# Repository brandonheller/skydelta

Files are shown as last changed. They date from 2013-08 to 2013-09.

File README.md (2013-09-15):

CAUTION: EXPERIMENTAL!

SkyDelta is a new type of 3D printer that employs tensioned lines for motion, rather than linear axes.  This repository includes all the OpenSCAD parts files needed to replicate the design and play with it yourself, under a [Creative Commons Attribution-NonCommercial license (CC BY-NC)](http://creativecommons.org/licenses/by-nc/3.0/). 

Designed by Brandon Heller in California (mostly, plus some design done over the Pacific).  The name refers to Skycam, which flies over football and athletic fields to provide great camera shots, using carefully-controlled high-tension lines.

SkyDelta builds on the triangular prism frame of an extrusion-based Linear Delta of your choice, like a Kossel Mini or Cerberus Pup.  It ditches the linear rails, carriages, ball joints, control rods, belts and pulleys.  It adds Spectra line, printed parts, bearings, standoffs, and three springs.

On the plus side, it can potentially be cheaper, simpler, and faster to build, plus yield a larger build envelope.  On the down side, it may be harder to calibrate, requires new firmware, and may simply not print well.  

Honestly, I don't know if it'll work, but it seems fun to try.  The parts are carefully designed and all have seen tweaks from printing and assembling them, but the whole assembly will likely need tuning.

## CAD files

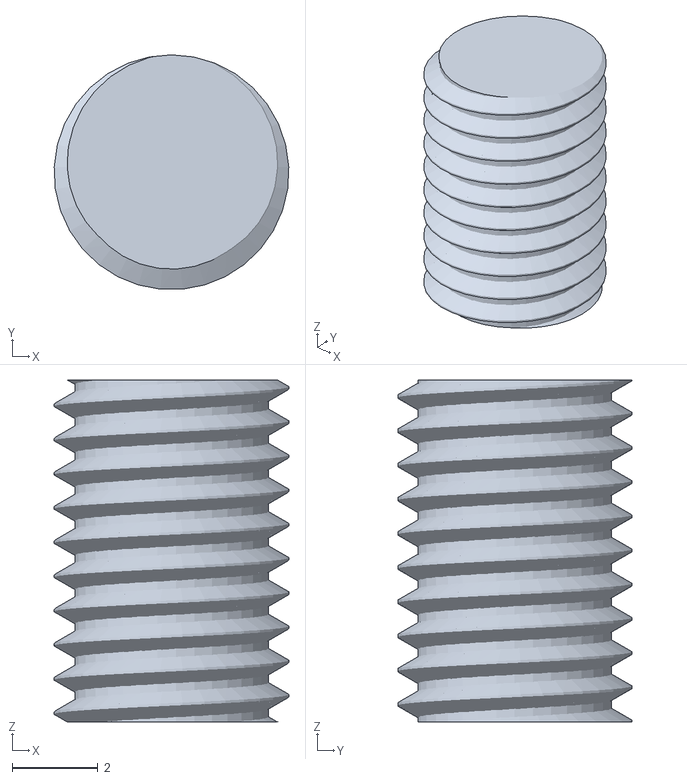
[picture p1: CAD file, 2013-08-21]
m5_internal.stl
5.49 x 5.48 x 8.00

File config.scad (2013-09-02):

delta = 0.1;  // Arbitrary small value to eliminate coincident-face visual artifcats.
big = 1000;  // Arbitrary large value to easy modeling of large stuff (usually for difference'ing).

extrusion_width = 15;
spool_r = 9; // Grabercars Kossel spools are 18mm measured at the center of the filament.

// Plastic colors
red = [1.0, 0, 0];  // bright red
black = [0.25, 0.25, 0.25];  // dark, but not too dark to show reflections
color = red;

// Screws/nuts
m3_r = (3.0+0.15)/2;  // A little slop to reduce need to drill out.  Use high $fn values.
m3_nut_r = (6.18+0.25)/2;
m3_nut_h = 2.5;
m3_screw_head_r = 6.5/2;
m3_thread_r = (3.0-0.5)/2; // Tight fit for thread-forming.
m3_cap_r = (5.0+0.3)/2;  // SHCS cap radius.
m3_cap_h = 3.0;  // SHCS cap height.
m3_thread_r = (2.8)/2;

// Effector key dimensions
effector_body_r = 18;  // Main cylinder radius.  Kossel Mini compatible.
mount_radius = 12.5;  // Hotend mounting screws, standard would be 25mm.  Kossel Mini compatible.

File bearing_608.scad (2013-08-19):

bearing_608_h = 7.0;
bearing_608_ir = 8.0/2;
bearing_608_or = 22.0/2;
bearing_608_color = [0.7, 0.7, 0.7, 1.0];
bearing_608_countersink_h = 0.5;  // 45-degree countersink height
bearing_608_countersink_r = 0.5;  // added to main IR

delta = 0.1;

$fn=32;

module bearing_608() {
	color(bearing_608_color) {
		difference() {
			cylinder(r=bearing_608_or, h=bearing_608_h);
			translate([0, 0, -delta]) cylinder(r=bearing_608_ir, h=bearing_608_h + 2 * delta);
			translate([0, 0, -delta]) cylinder(r1=bearing_608_ir+bearing_608_countersink_r, r2=bearing_608_ir, h=bearing_608_countersink_h);
			translate([0, 0, bearing_608_h+delta]) rotate([180, 0, 0]) cylinder(r1=bearing_608_ir+bearing_608_countersink_r, r2=bearing_608_ir, h=bearing_608_countersink_h);
		}
	}
}

//bearing_608();

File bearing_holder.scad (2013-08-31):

include <bearing_608.scad>;
include <config.scad>;

screw_r = 3.0/2;
bearing_base_thickness = 3.5;
height = bearing_608_h+bearing_base_thickness; // height in direction of bearing axis
bearing_width_clearance = 6.0;
width = bearing_608_or*2+bearing_width_clearance; 
length = bearing_608_or*2; // distance sticking out from OpenBeam
cutout_width = 8;
bearing_gap = 0.75; // space to clear bearing motion
extrusion_width = 15;
main_thickness = 3.0;
flange_height = 20;
flange_out = 20;
gap_width = 8;  // width of gap for bearing snap
bearing_608_or_adjust = -0.10;  // grab the bearing a bit tighter.
bounding_cyl_r = bearing_608_or+2.5;
pie_side_clearance = 3.0;  // amount of material on each side of the cutout "center pie"
pie_x_shift = 10;  // amount to shift the pie

big = 100;

delta = 1;

$fn = 128;

module bearing_holder() {
	difference() {
		intersection() {
			// Main body
			union() {
				// Body
				translate([0, 0, bearing_608_h/2-bearing_base_thickness/2]) cube([length, width, bearing_608_h + bearing_base_thickness], center=true);
				// Flange
				translate([-length/2, -extrusion_width/2, -flange_height-bearing_base_thickness]) cube([main_thickness, extrusion_width, flange_height]);
				// Side flange supports
				for (i = [-1, 1]) {
					translate([-length/2+flange_out/2, i*(extrusion_width/2-main_thickness/2), -bearing_base_thickness-flange_height/2]) 
	cube([flange_out, main_thickness, flange_height], center=true);
				}
			}
			// Cylinder to reduce interference when effector is close to the tower.
			cylinder(r=bounding_cyl_r, h=big, center=true);
		}
		// Primary bearing cutout
		cylinder(r=bearing_608_or+bearing_608_or_adjust, h=bearing_608_h + delta);
		// Cutout to avoid overly narrow paths
		translate([0, 0, bearing_608_h/2+delta/2]) cube([big, cutout_width, bearing_608_h + delta], center=true);
		// Center opening
		cylinder(r=bearing_608_ir, h=big, center=true);
		// Bearing gap
		translate([0, 0, -bearing_gap]) cylinder(r=bearing_608_or-3, h=big);
		// Gap for end of clip on idler mount
		translate([0, 0, -2.0]) cylinder(r=bearing_608_ir+2, h=big);
		// Cutout for easier bearing removal
		//translate([length/2-4, -4, -big/2]) cube([8, 8, big]);
		// Cutout so that part snaps around bearing
		translate([0, -gap_width/2, -big/2]) cube([big, gap_width, big]);
		// Holes for attaching to extrusion
		for (i = [-7, -20]) {
			translate([0, 0, i]) rotate([0, -90, 0]) cylinder(r=m3_r, h=big, center=true);
		}
		// Chop off bottom corner
		translate([-10, 0, -27]) rotate([0, 36, 0]) translate([0, -big/2, 0]) cube([big, big, big]);
		// "Center pie": Chop off front corner to add extra clearance
		hull() {
			translate([0, 0, -20]) rotate([0, 0, 30]) 
				translate([pie_x_shift, -pie_side_clearance, 0]) cube([big, pie_side_clearance*2, 40]);
			translate([0, 0, -20]) rotate([0, 0, -30]) 
				translate([pie_x_shift, -pie_side_clearance, 0]) cube([big, pie_side_clearance*2, 40]);
		}
		// Chop off a bit more of the front corner to save plastic
		translate([bearing_608_or-4.0, -big/2, -big/2]) cube([big, big, big]); 
	}
}

//rotate([0, -90, 0]) bearing_holder();
//bearing_608();

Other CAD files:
effector_assembly.scad
archives/effector_flange.scad
archives/effector_tube.scad
effector_base.scad
effector_flange.scad
effector_lower.scad
effector_rod.scad
effector_standoff.scad
effector_tensioner.scad
effector_tube.scad
effector_upper.scad
filament_assembly.scad
filament_hole_test.scad
filament_test.scad
filament_tube.scad
idler.scad
idler_mount.scad
jhead.scad
nema17_mount.scad
skydelta.scad
spool.scad
utl.NEMA.scad

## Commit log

2013-08-10 First commit: add idler mount
    [idler_mount.scad]
2013-08-10 Refactor bearing_608
    [bearing_608.scad, idler_mount.scad]
2013-08-10 Don't put bearing in by default
    [bearing_608.scad]
2013-08-10 Add prelim bearing holder design. Needs reinforcing
    [bearing_holder.scad]
2013-08-10 Improve flange on bearing holder
    [bearing_holder.scad]
2013-08-10 Lots of small fixes, plus addition of a complete assembly
    [bearing_608.scad, bearing_holder.scad, filament_assembly.scad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]
2013-08-10 Add spike assembly file
    [spike.scad]
2013-08-13 Cut an extra mm off idler mount to enable flat-side printing
    [idler_mount.scad]
2013-08-18 Refactoring before making double idler
    [config.scad, filament_assembly.scad, idler.scad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]
2013-08-18 Remove unneeded var
    [idler_mount.scad, idler_mount_single.scad]
2013-08-18 Turn solid cylinder ends into clips
    [idler_mount.scad, idler_mount_single.scad]
2013-08-18 Add bearing grips on edges, refactor
    [idler_mount.scad, idler_mount_single.scad]
2013-08-18 Refactoring toward double idler mount
    [idler_mount.scad, idler_mount_single.scad]
2013-08-18 Add double idler mount and make the design more generic in the process.
    [config.scad, idler_mount.scad, idler_mount_double.scad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]
2013-08-19 Small tweaks
    [filament_assembly.scad, idler_mount_double.scad, idler_mount_single.scad]
2013-08-19 Increase size of cutout in bearing holder
    [bearing_holder.scad]
2013-08-19 Add cutout to prevent filament interference at steep angles
    [idler_mount.scad]
2013-08-19 608 bearings are reall 22mm OD, not 25
    [bearing_608.scad]
2013-08-19 Add internal countersinks to 608 bearing
    [bearing_608.scad]
2013-08-19 Fix clip flange dims
    [idler_mount.scad]
2013-08-19 Add extra flange to later remove 608 bearing
    [idler_mount.scad]
2013-08-19 Bearing holder tweaks
    [bearing_holder.scad]
2013-08-19 Adjust idler dims to match real part
    [idler.scad]
2013-08-19 Minor bearing fix
    [bearing_608.scad]
2013-08-19 Tweaks to better fit the idlers I have
    [idler_mount.scad]
2013-08-21 Add first cut at tensionable NEMA17 mount
    [nema17_mount.scad]
2013-08-21 Add starter effector pieces
    These would definitely reduce the usable Z, but are simpler to design.
    [effector_cup.scad, effector_rod.scad, m5_internal.stl]
2013-08-21 Update a few config params
    [config.scad]
2013-08-21 Switch to double idlers and add a complete tube assembly
    [effector_cup.scad, effector_flange.scad, effector_tube.scad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]
2013-08-21 Lotsa updates; colorized, added spools, NEMA17, mounts
    [config.scad, effector_tube_assembly.scad, filament_assembly.scad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]
2013-08-21 Tweaks after first print
    [bearing_holder.scad, idler_mount.scad]
2013-08-21 Minor refactoring
    [config.scad, nema17_mount.scad]
2013-08-21 Minor tweaks
    [config.scad, effector_flange.scad]
2013-08-26 Remove minor duplication
    [spike.scad]
2013-08-26 Attempt to remove visual artifcats by reducing use of 'big'
    Doesn't actually seem to work unfortunately, but can't hurt.
    [effector_flange.scad]
2013-08-26 Minor tweak: tighten fit on J-head
    [effector_cup.scad]
2013-08-26 Add a few notes
    [config.scad]
2013-08-26 Increase hole size for better off-printer fit
    [config.scad]
2013-08-26 Rotate effector cup to fit J-head
    [effector_tube_assembly.scad]
2013-08-26 Add features to effector cup
    [effector_cup.scad]
2013-08-26 Add a few extra 'standard m3 dims' to config
    [config.scad]
2013-08-26 Grab bearing a bit tighter
    [bearing_holder.scad]
2013-08-26 Lotsa tweaks to bearing_holder after first print
    Remove potential interferences, tweak fit, remove material for faster prints
    [bearing_holder.scad]
2013-08-29 Add 'filament tube' test part
    [filament_test.scad]
2013-08-29 Comment out screw-head holes
    [effector_cup.scad]
2013-08-29 Move filament tube macro to its own file
    [filament_test.scad, filament_tube.scad]
2013-08-31 Add standoff mounts to effector
    [effector_cup.scad]
2013-08-31 Add extra beef between standoff mounts
    [effector_cup.scad]
2013-08-31 Minor rename
    [effector_lower.scad]
2013-08-31 Tweaks to smoothen edges
    [effector_lower.scad]
2013-08-31 Archive effector flange
    [effector_flange.scad]
2013-08-31 Refactor effector in base + upper,lower
    [effector_base.scad, effector_lower.scad, effector_upper.scad]
2013-08-31 Add effector tensioner with nut trap
    [effector_tensioner.scad]
2013-08-31 Add effector standoff
    [effector_standoff.scad, effector_tensioner.scad]
2013-08-31 Archive effector tube
    [effector_tube.scad]
2013-08-31 Rename effector assembly
    [effector_assembly.scad]
2013-08-31 Make a functional effector assembly.
    [effector_assembly.scad, effector_base.scad, effector_upper.scad]
2013-08-31 Positioning tweaks
    [spike.scad]
2013-09-01 Add simple straight-through filament size test block
    [filament_hole_test.scad]
2013-09-01 Implement easy tie-down scheme for effector pieces
    [effector_base.scad]
2013-09-02 Tweaks to tensioner after checking generated toolpaths
    [config.scad, effector_tensioner.scad]
2013-09-02 Tweaks to effector base for better filament path
    [effector_base.scad]
2013-09-02 Print larger sizes of holes for test
    [filament_hole_test.scad]
2013-09-02 Improve standoff printability
    Long perimeter runs should be faster, prettier, and more stable than
    vertically printed standoffs.
    [config.scad, effector_standoff.scad]
2013-09-02 Slightly increase standoff size
    [effector_standoff.scad]
2013-09-02 Increase hole for filament in tensioner
    [effector_tensioner.scad]
2013-09-15 Rename to SkyDelta
    [skydelta.scad]
2013-09-16 Rename module
    [skydelta.scad]
